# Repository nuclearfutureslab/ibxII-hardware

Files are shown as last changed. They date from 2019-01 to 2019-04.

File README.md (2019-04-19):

# IBX ]\[ Hardware

IBX ]\[ is an information barrier setup for nuclear warhead verification with an Apple II ([Details](http://www.vintageverification.org)).
This repository contains schematics and layout files for two custom Apple II peripheral cards.

The KiCad files use the [Apple \]\[ Edge Connector Template](http://www.xjmaas.nl/my-apple-collection/apple-edge-connector-template-for-kicad/), best place it inside the directory as (Apple2_Bus).

## ADC Board
Apple II peripheral card for A/D conversion of signals from radiation detectors (scintillator/photo multiplier combination). The card includes all necessary parts - pre-amplifier, amplification & pulse shaping, peak-detect and hold circuit, ADC timing circuit. The current revision is improved to use full +12V/-12V components all the way to the ADC. Previous versions included 8 LEDs that can be toggled by writing to a specific Apple II memory location, but these have been removed now.

[Rev. 3 Board at OSHPark repository](https://oshpark.com/shared_projects/9M42SHV2)
[Rev. 1 Board at OSHPark repository](https://oshpark.com/shared_projects/9M42SHV2)

### Address scheme (has to be offset by address of card slot, eg. 49344 for Slot 4):

| Address | R/W | Function |
|----| ----|----|
| 01 | (Read) | Reset trigger circuit, make it ready for a new incoming pulse |
| 02 | (Read) | Read low byte of ADC value |
| 03 | (Read) | Read high byte of ADC value |
| 04 | (Read) | Read status buffer for ADC |

## HV Board

Apple II peripheral card to provide high voltage supply to devices (e.g. Photo Multiplier tubes). The voltage is adjustable by writing an 8bit value to a memory address. It produces a voltage from 0-5V depending on this value, which gets converted into highvoltage by a CAEN 7505P module. 

[Rev. 1 Board at OSHPark repository](https://oshpark.com/shared_projects/YkaW1fvx)

### Address scheme (has to be offset by address of card slot, eg. 49312 for Slot 2):

| Address | R/W | Function |
|----| ----|----|
00 | (Write) | Address to write a value for DA
01 | (Read) | enable HV 
02 | (Read) | disable HV

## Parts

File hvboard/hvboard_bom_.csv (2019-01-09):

Component | Description | Part | References | Value | Footprint | Quantity Per PCB | Datasheet | DigiKey
1 |  | A2_BUS | BUS101 | A2_BUS | BUS_A2 | 1
2 | Unpolarized capacitor, small symbol | C_Small | C101 C103 C105 C106 C107 C109 | 0.1µF | FG18 | 6 | https://product.tdk.com/info/en/documents/chara_sheet/FG18X7R1H104KNT06.pdf | 445-173265-1-ND
3 | Unpolarized capacitor, small symbol | C_Small | C110 | 0.47µF | FG18 | 1 | https://product.tdk.com/info/en/documents/chara_sheet/FG18X7R1H474KRT06.pdf | 445-173276-1-ND
4 | Unpolarized capacitor, small symbol | C_Small | C104 C108 | 2.2µF | FG14 | 2 | https://product.tdk.com/info/en/documents/chara_sheet/FG14X7R1H225KRT06.pdf | 445-173138-1-ND
5 | Polarized capacitor, small US symbol | CP1_Small | C102 | 47µF | CP_Radial_D6.3mm_P2.50mm | 1 | https://industrial.panasonic.com/cdbs/www-data/pdf/RDF0000/ABA0000C1022.pdf | P15400-ND
6 | Light emitting diode | LED | D101 | LED | LED_D5.0mm | 1 | https://www.lumex.com/content/files/ProductAttachment/SSL-LX5093SID.pdf | 67-2288-ND
7 | Resettable fuse, polymeric positive temperature coefficient, small symbol | Polyfuse_Small | F101 F103 | Polyfuse_Small | Fuse_TE5_Littlefuse-395Series | 2 | https://product.tdk.com/info/en/documents/data_sheet/55/db/PTC/PTC_OC_Leaded_12V_24V_C935_C995.pdf | 495-3904-ND
8 | Generic connector, single row, 01x01, script generated (kicad-library-utils/schlib/autogen/connector/) | Conn_01x01 | J101 | Debug-1 | Socket_Strip_Straight_1x01_Pitch2.54mm | 1
9 | Generic connector, single row, 01x05, script generated (kicad-library-utils/schlib/autogen/connector/) | Conn_01x05 | J103 | Debug-2 | Pin_Header_Straight_1x05_Pitch2.54mm | 1
10 | coaxial connector (BNC, SMA, SMB, SMC, Cinch/RCA, ...) | Conn_Coaxial | J102 | HV | HVConnector3D | 1
11 | Resistor, small symbol | R_Small | R128 | 0 | Resistor | 1
12 | Resistor | R | R116 R118 R124 | 10k | Resistor | 3 | http://www.vishay.com/docs/28724/mrs16m25.pdf | PPC10.0KZCT-ND
13 | Resistor | R | R103 R105 R107 R109 R111 R113 R115 | 10k+ | Resistor | 7 | http://www.vishay.com/docs/28767/mbsmapre.pdf | BC4515CT-ND
14 | Resistor, small symbol | R_Small | R123 | 1M | Resistor | 1 | http://www.vishay.com/docs/28724/mrs16m25.pdf | BC3959CT-ND
15 | Resistor | R | R101 R102 R104 R106 R108 R110 R112 R114 R117 | 20k | Resistor | 9 | http://www.vishay.com/docs/28767/mbsmapre.pdf | BC4511CT-ND
16 | Resistor, small symbol | R_Small | R119 | 470 | Resistor | 1 | http://www.vishay.com/docs/28724/mrs16m25.pdf | BC4173CT-ND
17 | Resistor, small symbol | R_Small | R120 R121 R125 | 4k7 | Resistor | 3 | http://www.vishay.com/docs/28724/mrs16m25.pdf | BC4176CT-ND
18 | Resistor | R | R122 | 8k2 | Resistor | 1 | http://www.vishay.com/docs/28724/mrs16m25.pdf | BC4264CT-ND
19 | quad 2-input NAND gate | 7400 | U104 U105 | 74HCT00 | DIP-14 | 2 | http://www.ti.com/lit/gpn/sn74ls00 | 296-2081-5-ND
20 | Decoder 3 to 8 active low outputs | 74LS138 | U108 | 74HCT138 | DIP-16_W7.62mm | 1 | http://www.ti.com/lit/ds/symlink/cd74hc138.pdf | 296-2091-5-ND
21 | Hex inverter schmitt trigger | 74HC14 | U102 | 74HCT14 | DIP-14 | 1 | http://www.nxp.com/documents/data_sheet/74HC_HCT04.pdf | 296-2093-5-ND
22 | Dual D Flip-flop, Set & Reset | 74HC74 | U103 | 74HCT74 | DIP-14 | 1 | http://www.ti.com/lit/ds/symlink/cd74hc74.pdf | 296-2132-5-ND
23 | 8-bit Register, 3-state outputs | 74LS374 | U106 | 74LS374 | DIP-20_W7.62mm | 1 | http://www.ti.com/lit/ds/symlink/cd74hct374.pdf | 296-2115-5-ND
24 |  | AD584 | U101 | AD584 | DIP-8 | 1 | https://www.analog.com/media/en/technical-documentation/data-sheets/AD584.pdf | AD584KNZ-ND
25 |  | CHV | U107 | CHV | CHV-rev2 | 1
Component Groups: | 25
Component Count: | 51
Fitted Components: | 51
Number of PCBs: | 1
Total components: | 51
Schematic Version:
Schematic Date:
BoM Date: | Wed 09 Jan 2019 12:07:31 AM EST
Schematic Source: | /home/moritz/Sync/gdrive_princeton/workprojects/vintageibx/appleIIdev/ibxII-hardware/hvboard/hvboard.sch
KiCad Version: | Eeschema 5.0.2-bee76a0~70~ubuntu18.04.1

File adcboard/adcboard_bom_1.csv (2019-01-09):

Component | Description | Part | References | Value | Footprint | Quantity Per PCB | Datasheet | DigiKey
1 |  | A2_BUS | BUS1 | A2_BUS | BUS_ADC | 1
2 | Unpolarized capacitor, small symbol | C_Small | C5 C6 C9 C13 C19 C20 C21 C22 C23 C24 C25 C34 C35 | 100nF | FG18 | 13 | https://product.tdk.com/info/en/documents/chara_sheet/FG18X7R1H104KNT06.pdf | 445-173265-1-ND
3 | Unpolarized capacitor, small symbol | C_Small | C3 C4 C14 C18 C29 C30 C40 C41 C45 C46 | 10nF | FG18 | 10 | https://product.tdk.com/info/en/documents/chara_sheet/FG18X7R1H103KNT06.pdf | 445-173172-1-ND
4 | Unpolarized capacitor, small symbol | C_Small | C7 C10 | 10pF | FG18 | 2 | https://product.tdk.com/info/en/documents/chara_sheet/FG18C0G1H100DNT06.pdf | 445-173169-1-ND
5 | Unpolarized capacitor, small symbol | C_Small | C12 C16 C17 | 10µF | FG16 | 3 | https://product.tdk.com/info/en/documents/chara_sheet/FG16X5R1H106KRT06.pdf | 445-173153-1-ND
6 | Unpolarized capacitor, small symbol | C_Small | C31 C32 | 1µF | FG18 | 2 | https://product.tdk.com/info/en/documents/chara_sheet/FG18X5R1H105KRT06.pdf | 445-173257-1-ND
7 | Unpolarized capacitor, small symbol | C_Small | C11 | 2.2nF | FG18 | 1 | https://product.tdk.com/info/en/documents/chara_sheet/FG18C0G1H222JNT06.pdf | 445-173184-1-ND
8 | Unpolarized capacitor, small symbol | C_Small | C27 C28 C38 C39 | 2.2µF | FG14 | 4 | https://product.tdk.com/info/en/documents/chara_sheet/FG14X7R1H225KRT06.pdf | 445-173138-1-ND
9 | Unpolarized capacitor, small symbol | C_Small | C1 C2 C43 C44 | 3.3µF | FG14 | 4 | https://product.tdk.com/info/en/documents/chara_sheet/FG14X5R1H335KRT06.pdf | 445-173130-1-ND
10 | Unpolarized capacitor, small symbol | C_Small | C15 | 330pF | FG18 | 1 | https://product.tdk.com/info/en/documents/chara_sheet/FG18C0G1H331JNT06.pdf | 445-173190-1-ND
11 | Unpolarized capacitor, small symbol | C_Small | C26 C36 C37 C42 | 470pF | FG28 | 4 | https://product.tdk.com/info/en/documents/chara_sheet/FG28C0G1H471JNT06.pdf | 445-173500-1-ND
12 | Unpolarized capacitor, small symbol | C_Small | C8 | 470pF | FG18 | 1 | https://product.tdk.com/info/en/documents/chara_sheet/FG18C0G1H471JNT06.pdf | 445-173197-1-ND
13 | Unpolarized capacitor, small symbol | C_Small | C33 | 47pF | FG28 | 1 | https://product.tdk.com/info/en/documents/chara_sheet/FG28C0G1H470JNT06.pdf | 445-173499-1-ND
14 | Zener diode, small symbol | D_Zener_Small | D5 | D_Zener_Small | D_DO-35_SOD27_P7.62mm_Horizontal | 1 | http://www.vishay.com/docs/85604/bzx55-se.pdf | BZX55B10-TRGICT-ND
15 | Light emitting diode, small symbol | LED_Small | D4 | LED_Small | LED_D5.0mm | 1 | https://www.lumex.com/content/files/ProductAttachment/SSL-LX5093USBD.pdf | 67-1751-ND
16 | Schottky diode, small symbol | D_Schottky_Small | D1 D2 D3 | SD103A | D_DO-35_SOD27_P7.62mm_Horizontal | 3 | http://www.vishay.com/docs/85754/sd103a.pdf | SD103AVSCT-ND
17 | Resettable fuse, polymeric positive temperature coefficient, small symbol | Polyfuse_Small | F2 | HC:120mA | Fuse_Littelfuse_395Series | 1 | https://product.tdk.com/info/en/documents/data_sheet/55/db/PTC/PTC_OC_Leaded_12V_24V_C935_C995.pdf | 495-3907-ND
18 | Resettable fuse, polymeric positive temperature coefficient, small symbol | Polyfuse_Small | F1 F3 | HC:250mA | Fuse_Littelfuse_395Series | 2 | https://product.tdk.com/info/en/documents/data_sheet/55/db/PTC/PTC_OC_Leaded_12V_24V_C935_C995.pdf | 495-3904-ND
19 | coaxial connector (BNC, SMA, SMB, SMC, Cinch/RCA, ...) | Conn_Coaxial | J2 | Detector | BNC_Socket_TYCO-AMP_LargePads | 1 | https://www.te.com/commerce/DocumentDelivery/DDEController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 | A97555-ND
20 | Generic connector, single row, 01x03, script generated (kicad-library-utils/schlib/autogen/connector/) | Conn_01x03 | J4 | SigADC | 3-Pin-Header | 1 | ~
21 | Generic connector, single row, 01x03, script generated (kicad-library-utils/schlib/autogen/connector/) | Conn_01x03 | J8 | SigDiff | 3-Pin-Header | 1 | ~
22 | Generic connector, single row, 01x03, script generated (kicad-library-utils/schlib/autogen/connector/) | Conn_01x03 | J5 | SigF1 | 3-Pin-Header | 1 | ~
23 | Generic connector, single row, 01x03, script generated (kicad-library-utils/schlib/autogen/connector/) | Conn_01x03 | J7 | SigF2 | 3-Pin-Header | 1 | ~
24 | Generic connector, single row, 01x03, script generated (kicad-library-utils/schlib/autogen/connector/) | Conn_01x03 | J9 | SigF3 | 3-Pin-Header | 1 | ~
25 | Generic connector, single row, 01x03, script generated (kicad-library-utils/schlib/autogen/connector/) | Conn_01x03 | J10 | SigInv | 3-Pin-Header | 1 | ~
26 | Generic connector, single row, 01x03, script generated (kicad-library-utils/schlib/autogen/connector/) | Conn_01x03 | J1 | SigOut | 3-Pin-Header | 1 | ~
27 | Generic connector, single row, 01x03, script generated (kicad-library-utils/schlib/autogen/connector/) | Conn_01x03 | J6 | SigP | 3-Pin-Header | 1 | ~
28 | Generic connector, single row, 01x03, script generated (kicad-library-utils/schlib/autogen/connector/) | Conn_01x03 | J3 | TrigLvl | 3-Pin-Header | 1 | ~
29 | Resistor, small symbol | R_Small | R7 R9 R11 | 100 | Resistor | 3 | http://www.vishay.com/docs/28724/mrs16m25.pdf | BC3952CT-ND
30 | Resistor, small symbol | R_Small | R10 R13 R28 | 10k | Resistor | 3 | http://www.vishay.com/docs/28724/mrs16m25.pdf | PPC10.0KZCT-ND
31 | Resistor, small symbol | R_Small | R21 | 150k | Resistor | 1 | http://www.vishay.com/docs/28724/mrs16m25.pdf | PPC150KZCT-ND
32 | Resistor, small symbol | R_Small | R23 R27 R32 | 15k | Resistor | 3 | http://www.vishay.com/docs/28724/mrs16m25.pdf | BC4005CT-ND
33 | Resistor, small symbol | R_Small | R3 | 1k | Resistor | 1 | http://www.vishay.com/docs/28724/mrs16m25.pdf | PPC1.00KZCT-ND
34 | Resistor, small symbol | R_Small | R6 | 200 | Resistor | 1 | http://www.vishay.com/docs/28724/mrs16m25.pdf | BC4039CT-ND
35 | Resistor, small symbol | R_Small | R22 R26 R31 | 20k | Resistor | 3 | http://www.vishay.com/docs/28724/mrs16m25.pdf | PPC20.0KZCT-ND
36 | Resistor, small symbol | R_Small | R8 | 330 | Resistor | 1 | http://www.vishay.com/docs/28724/mrs16m25.pdf | BC4123CT-ND
37 | Resistor, small symbol | R_Small | R2 R30 | 47k | Resistor | 2 | http://www.vishay.com/docs/28724/mrs16m25.pdf | BC4178CT-ND
38 | Resistor, small symbol | R_Small | R18 R19 | 49.9 | Resistor | 2 | http://www.vishay.com/docs/28724/mrs16m25.pdf | BC4639CT-ND
39 | Resistor, small symbol | R_Small | R12 R14 R15 R16 R17 R33 | 4k7 | Resistor | 6 | http://www.vishay.com/docs/28724/mrs16m25.pdf | BC4176CT-ND
40 | Resistor, small symbol | R_Small | R4 | 510 | Resistor | 1 | http://www.vishay.com/docs/28724/mrs16m25.pdf | BC4190CT-ND
41 | Resistor, small symbol | R_Small | R1 R5 | 6k8 | Resistor | 2 | http://www.vishay.com/docs/28724/mrs16m25.pdf | BC4239CT-ND
42 | Resistor, small symbol | R_Small | R20 R24 R25 R29 | 8k2 | Resistor | 4 | http://www.vishay.com/docs/28724/mrs16m25.pdf | BC4264CT-ND
43 | Potentiometer | R_POT | RV2 | 100k | Potentiometer_Bourns_3006P_Horizontal | 1 | https://www.bourns.com/docs/Product-Datasheets/3006.pdf | 3006P-104LF-ND
44 | Potentiometer | R_POT | RV1 | 50k | Potentiometer_Bourns_3006P_Horizontal | 1 | https://www.bourns.com/docs/Product-Datasheets/3006.pdf | 3006P-503LF-ND
45 | quad 2-input NAND gate | 7400 | U6 U7 | 74HCT00 | DIP-14 | 2 | http://www.ti.com/lit/ds/symlink/cd74hc74.pdf | 296-2081-5-ND
46 | hex inverter | 74HC04 | U5 U9 | 74HCT04 | DIP-14 | 2 | http://www.ti.com/lit/ds/symlink/cd74hc04.pdf | 296-2083-5-ND
47 | Decoder 3 to 8 active low outputs | 74LS138 | U8 | 74HCT138 | DIP-16_W7.62mm_Socket | 1 | http://www.ti.com/lit/ds/symlink/cd74hc138.pdf | 296-2091-5-ND
48 | 8-bit Buffer/Line Driver 3-state | 74HC244 | U11 | 74HCT244 | DIP-20_W7.62mm_Socket | 1 | http://www.ti.com/lit/ds/symlink/cd74hc240.pdf | 296-2104-5-ND
49 | Dual D Flip-flop, Set & Reset | 74HC74 | U4 | 74HCT74 | DIP-14 | 1 | http://www.ti.com/lit/ds/symlink/cd74hc74.pdf | 296-2132-5-ND
50 | Single Rail-to-Rail High Output Current Operational Amplifiers, SOIC-8 | OP179GS | U13 | AD744 | DIP-8 | 1 | http://www.analog.com/media/en/technical-documentation/data-sheets/OP179_279.pdf | AD744KNZ-ND
51 |  | AD790 | U3 | AD790 | DIP-8 | 1 | https://www.analog.com/media/en/technical-documentation/data-sheets/AD790.pdf | AD790JNZ-ND
52 | Dual operational amplifier | Opamp_Dual_Generic | U1 | AD826 | DIP-8 | 1 | https://www.analog.com/media/en/technical-documentation/data-sheets/AD826.pdf | AD826ANZ-ND
53 | Dual High Speed, Low Power, Low Distortion, Voltage Feedback Amplifiers, DIP-8/SOIC-8 | LM6172 | U15 | AD826 | DIP-8 | 1 | https://www.analog.com/media/en/technical-documentation/data-sheets/AD826.pdf | AD826ANZ-ND
54 |  | ADC-AD1674 | U10 | ADC-AD1674 | DIP-28_W15.24mm_Socket | 1 | https://www.analog.com/media/en/technical-documentation/data-sheets/AD1674.pdf | AD1674JNZ-ND
55 | Single SPST Monolithic CMOS Analog Switch, normally OFF, 20Ohm Ron, DIP-8 | DG418xJ | U2 | DG418 | DIP-8 | 1 | http://www.vishay.com/docs/70051/dg417.pdf | DG418DJ-E3-ND
56 | Dual High Speed, Low Power, Low Distortion, Voltage Feedback Amplifiers, DIP-8/SOIC-8 | LM6172 | U12 U14 | LM6172 | DIP-8 | 2 | http://www.ti.com/lit/ds/symlink/lm6172.pdf | LM6172IN/NOPB-ND
Component Groups: | 56
Component Count: | 115
Fitted Components: | 115
Number of PCBs: | 1
Total components: | 115
Schematic Version: | 1
Schematic Date: | 2017-11-28
BoM Date: | Tue 08 Jan 2019 11:19:12 PM EST
Schematic Source: | /home/moritz/Sync/gdrive_princeton/workprojects/vintageibx/appleIIdev/ibxII-hardware/adcboard/adcboard.sch
KiCad Version: | Eeschema 5.0.2-bee76a0~70~ubuntu18.04.1

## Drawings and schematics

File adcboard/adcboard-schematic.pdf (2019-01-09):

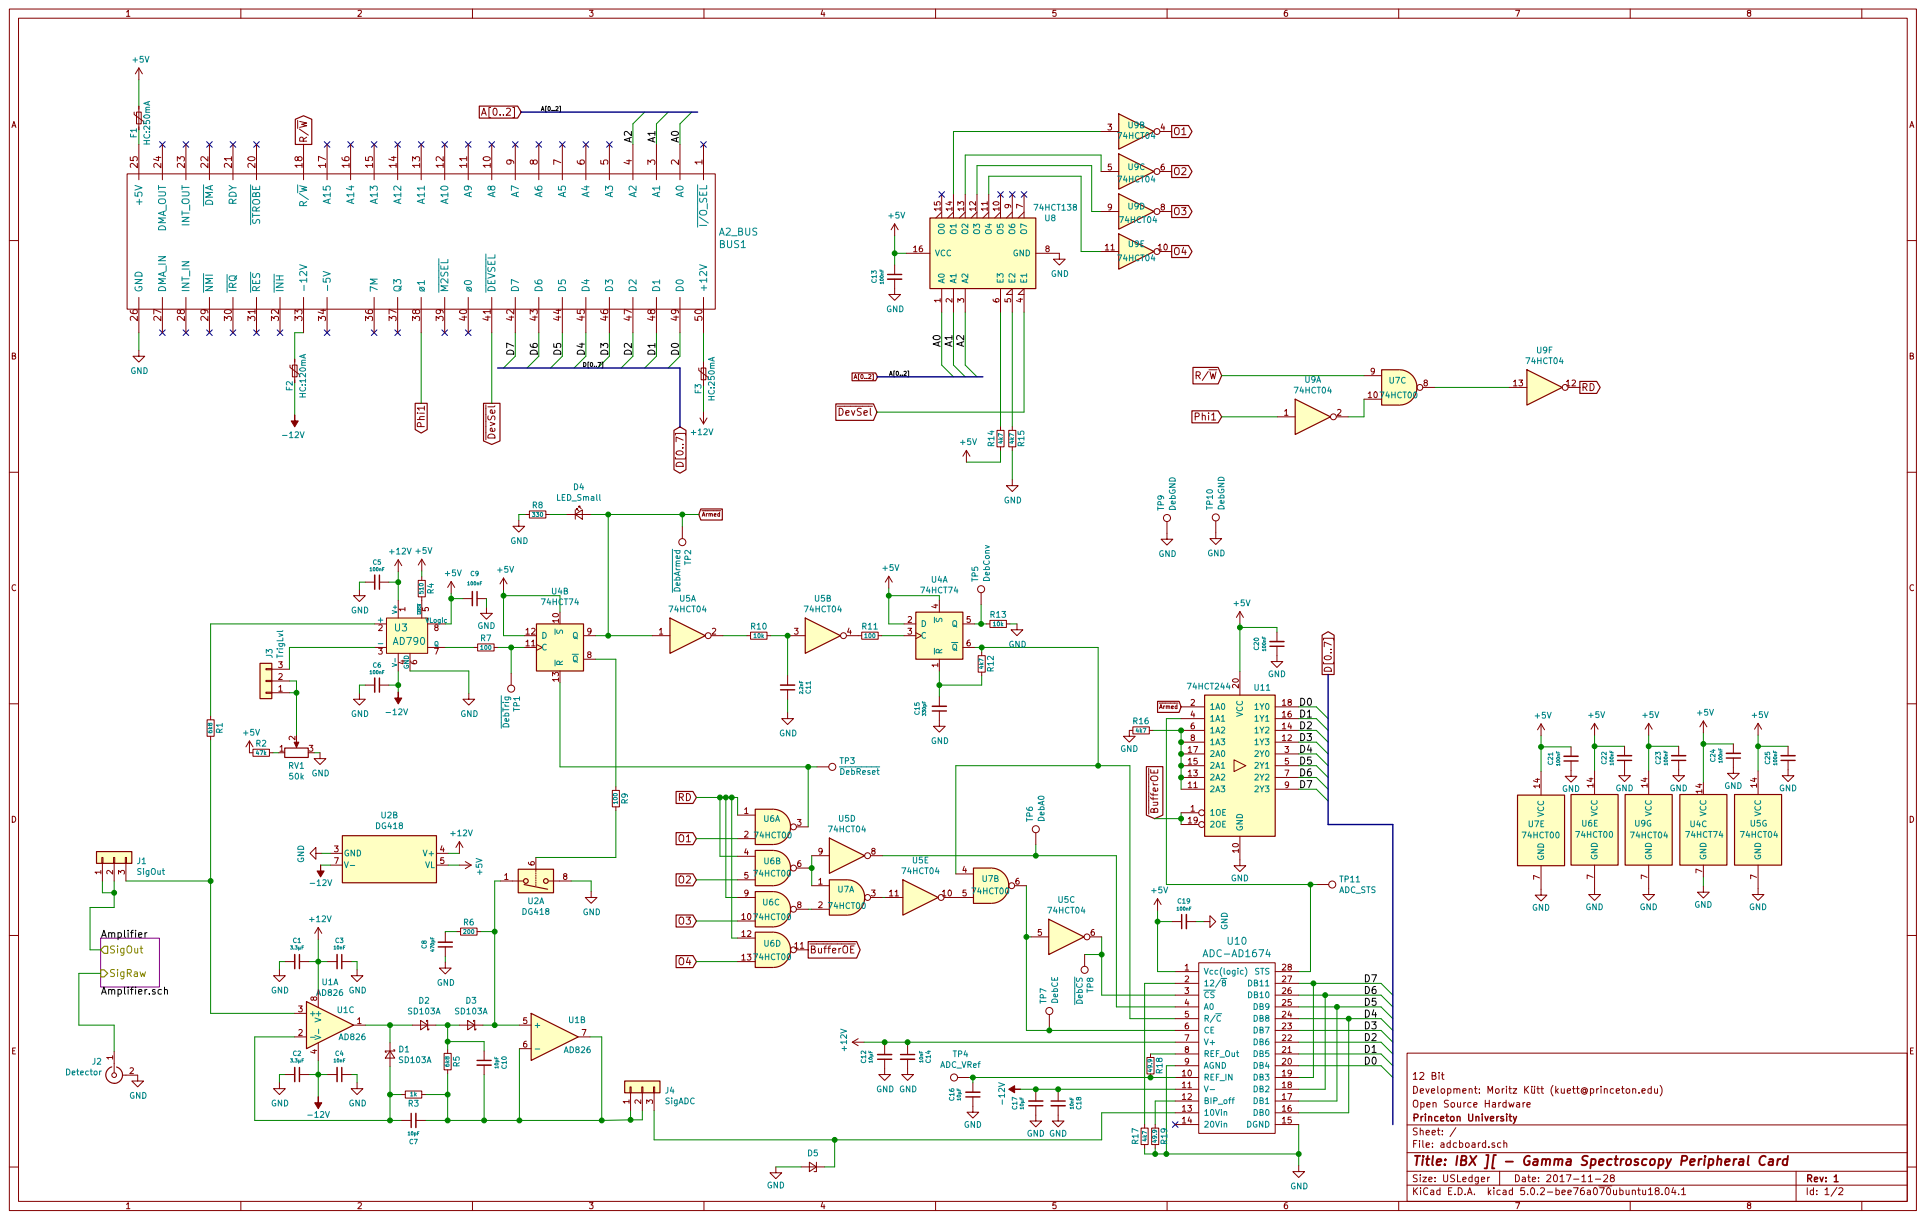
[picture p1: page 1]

9 A8 10 STROBE 20 IRQ 30 ø0 40 +12V 50 A9 11 RDY 21 RES 31 DEVSEL 41 A10 12 DMA 22 INH 32 D7 42 A11 13 INT_OUT 23 -12V 33 D6 43 A12 14 DMA_OUT 24 -5V 34 D5 44 A13 15 +5V 25 D4 45 A14 16 GND 26 7M 36 D3 46 A15 17 DMA_IN 27 Q3 37 D2 47 R/W 18 INT_IN 28 ø1 38 D1 48 NMI 29 M2SEL 39 D0 49 BUS1 A2_BUS

File: adcboard.sch Sheet: / Princeton University Open Source Hardware Development: Moritz Kütt (kuett@princeton.edu) 12 Bit A0A1A2

Amplifier Amplifier.sch SigRaw

Id: 1/2 Title: IBX ][ - Gamma Spectroscopy Peripheral Card

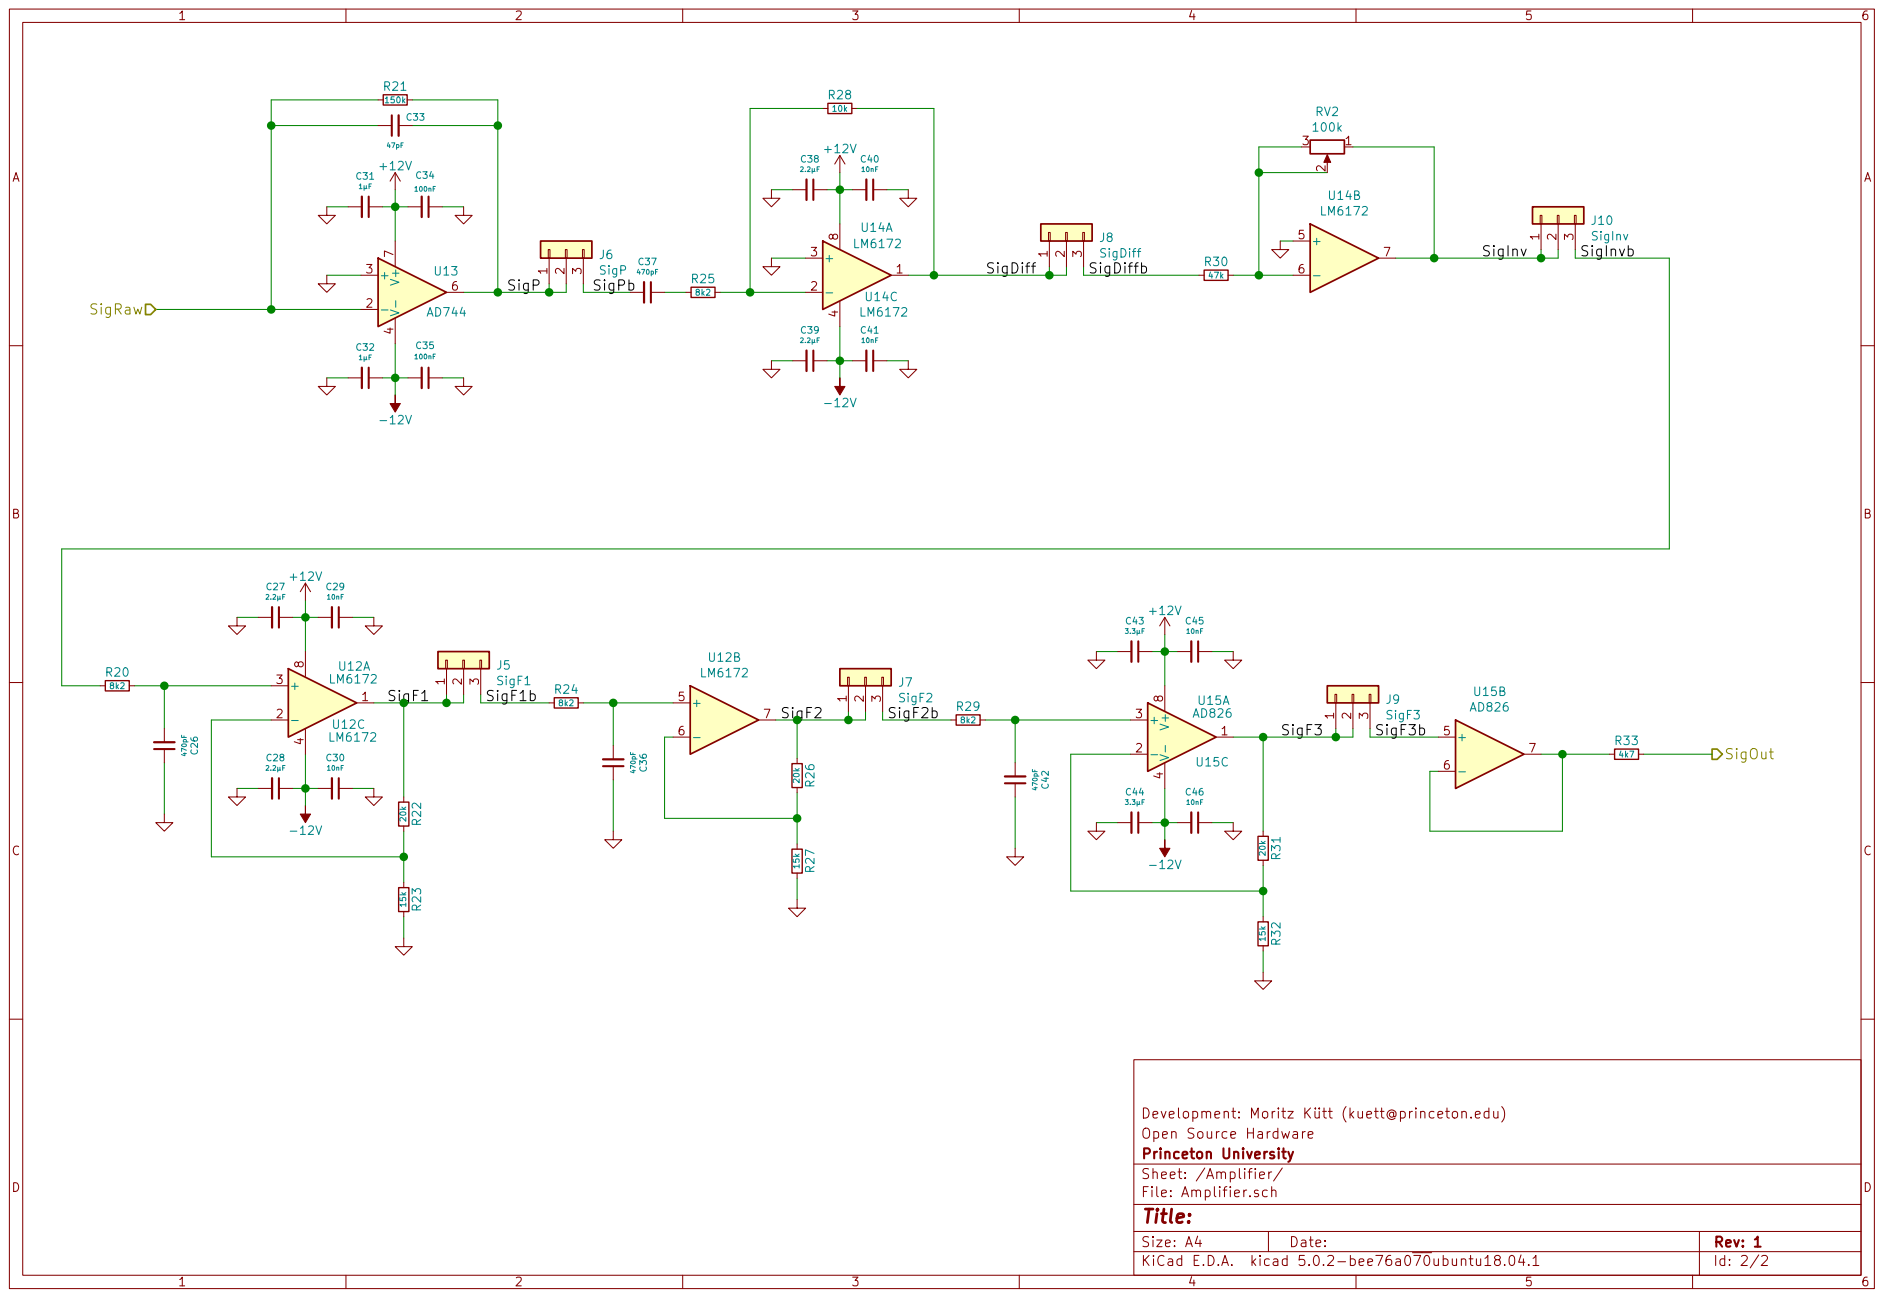
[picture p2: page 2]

Development: Moritz Kütt (kuett@princeton.edu)
Open Source Hardware
Princeton University
Sheet: /Amplifier/
File: Amplifier.sch
Id: 2/2 Title:

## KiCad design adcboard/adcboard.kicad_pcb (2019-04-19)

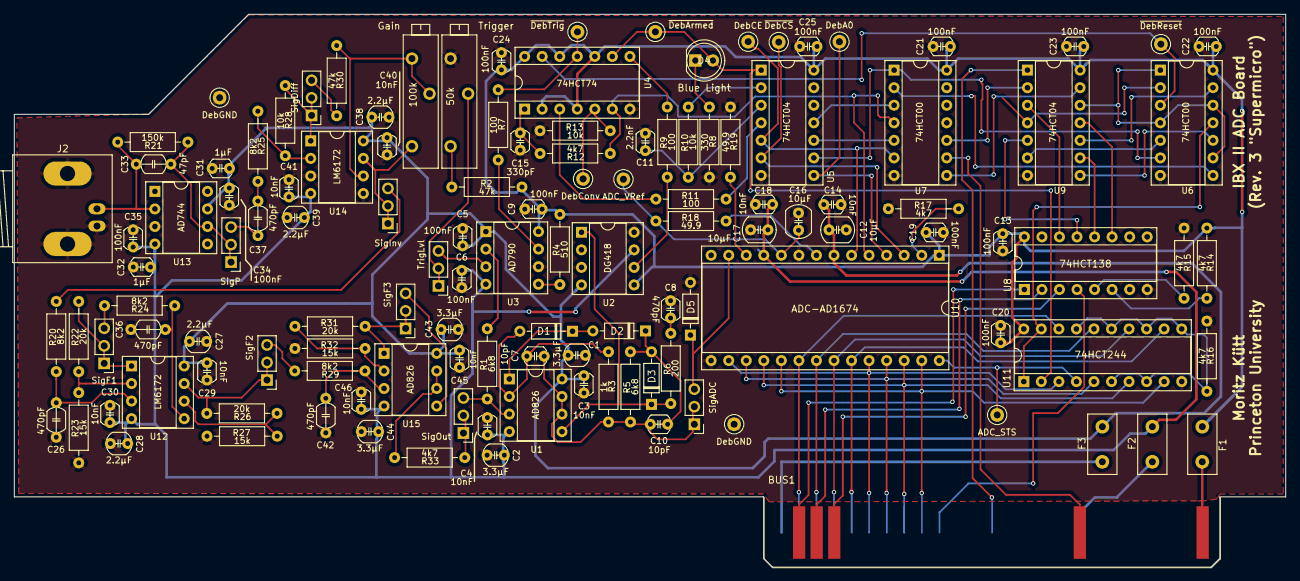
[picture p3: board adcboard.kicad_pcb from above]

Board: 2 copper layers, 184.0 x 80.0 mm, 126 parts (0 on the bottom side), 99 nets.

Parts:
BUS1: A2_BUS; BUS_ADC
C1, C2, C43, C44: 3.3µF; FG14
C3, C4, C14, C18, C29, C30, C40, C41, C45, C46: 10nF; FG18
C5, C6, C9, C13, C19, C20, C21, C22, C23, C24, C25, C34, C35: 100nF; FG18
C7, C10: 10pF; FG18
C8: 470pF; FG18
C11: 2.2nF; FG18
C12, C16, C17: 10µF; FG16
C15: 330pF; FG18
C26, C36, C37, C42: 470pF; FG28
C27, C28, C38, C39: 2.2µF; FG14
C31, C32: 1µF; FG18
C33: 47pF; FG28
D1, D2, D3: SD103A; D_DO-35_SOD27_P7.62mm_Horizontal
D4: Blue Light; LED_D5.0mm
D5: D_Zener_Small; D_DO-35_SOD27_P7.62mm_Horizontal
F1, F3: HC:250mA; Fuse_Littelfuse_395Series
F2: HC:120mA; Fuse_Littelfuse_395Series
Gain: 100k; Potentiometer_Bourns_3006P_Horizontal
J1: SigOut; 3-Pin-Header
J2: Detector; BNC_Socket_TYCO-AMP_LargePads
J3: TrigLvl; 3-Pin-Header
J4: SigADC; 3-Pin-Header
J5: SigF1; 3-Pin-Header
J6: SigP; 3-Pin-Header
J7: SigF2; 3-Pin-Header
J8: SigDiff; 3-Pin-Header
J9: SigF3; 3-Pin-Header
J10: SigInv; 3-Pin-Header
R1, R5: 6k8; Resistor
R2, R30: 47k; Resistor
R3: 1k; Resistor
R4: 510; Resistor
R6: 200; Resistor
R7, R9, R11: 100; Resistor
R8: 330; Resistor
R10, R13, R28: 10k; Resistor
R12, R14, R15, R16, R17, R33: 4k7; Resistor
R18, R19: 49.9; Resistor
R20, R24, R25, R29: 8k2; Resistor
R21: 150k; Resistor
R22, R26, R31: 20k; Resistor
R23, R27, R32: 15k; Resistor
TP1: ~DebTrig; TP
TP2: ~DebArmed; TP
TP3: ~DebReset; TP
TP4: ADC_VRef; TP
TP5: DebConv; TP
TP6: DebA0; TP
TP7: DebCE; TP
TP8: ~DebCS; TP
TP9, TP10: DebGND; TP
TP11: ADC_STS; TP
Trigger: 50k; Potentiometer_Bourns_3006P_Horizontal
U1, U15: AD826; DIP-8
U2: DG418; DIP-8
U3: AD790; DIP-8
U4: 74HCT74; DIP-14
U5, U9: 74HCT04; DIP-14
U6, U7: 74HCT00; DIP-14
U8: 74HCT138; DIP-16_W7.62mm_Socket
U10: ADC-AD1674; DIP-28_W15.24mm_Socket
U11: 74HCT244; DIP-20_W7.62mm_Socket
U12, U14: LM6172; DIP-8
U13: AD744; DIP-8

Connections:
+5V: C9.2, C13.1, C19.1, C20.2, C21.2, C22.2, C23.2, C24.2, C25.2, F1.1, R2.2, R4.2, R14.1, U2.5, U3.8, U4.2, U4.4, U4.10, U4.12, U4.14, U5.14, U6.14, U7.14, U8.16, U9.14, U10.1, U11.20
+12V: C1.1, C3.2, C5.1, C12.2, C14.1, C27.1, C29.2, C31.1, C34.2, C38.1, C40.2, C43.1, C45.2, F3.2, U1.8, U2.4, U3.1, U10.7, U12.8, U13.7, U14.8, U15.8
-12V: C2.1, C4.2, C6.1, C17.2, C18.1, C28.1, C30.2, C32.1, C35.2, C39.1, C41.2, C44.1, C46.2, F2.2, U1.4, U2.7, U3.4, U10.11, U12.4, U13.4, U14.4, U15.4
/Amplifier/SigDiff: J8.1, J8.2, R28.1, U14.1
/Amplifier/SigDiffb: J8.3, R30.2
/Amplifier/SigF1: J5.1, J5.2, R22.2, U12.1
/Amplifier/SigF1b: J5.3, R24.2
/Amplifier/SigF2: J7.1, J7.2, R26.2, U12.7
/Amplifier/SigF2b: J7.3, R29.2
/Amplifier/SigF3: J9.1, J9.2, R31.2, U15.1
/Amplifier/SigF3b: J9.3, U15.5
/Amplifier/SigInv: Gain.1, J10.1, J10.2, U14.7
/Amplifier/SigInvb: J10.3, R20.2
/Amplifier/SigOut: J1.1, J1.2, R33.1
/Amplifier/SigP: C33.2, J6.1, J6.2, R21.1, U13.6
/Amplifier/SigPb: C37.2, J6.3
/Amplifier/SigRaw: C33.1, J2.1, R21.2, U13.2
A0: BUS1.2, U8.1
A1: BUS1.3, U8.2
A2: BUS1.4, U8.3
D0: BUS1.49, U10.20, U11.18
D1: BUS1.48, U10.21, U11.16
D2: BUS1.47, U10.22, U11.14
D3: BUS1.46, U10.23, U11.12
D4: BUS1.45, U10.16, U10.24, U11.3
D5: BUS1.44, U10.17, U10.25, U11.5
D6: BUS1.43, U10.18, U10.26, U11.7
D7: BUS1.42, U10.19, U10.27, U11.9
GND: BUS1.26, C1.2, C2.2, C3.1, C4.1, C5.2, C6.2, C8.1, C9.1, C11.1, C12.1, C13.2, C14.2, C15.1, C16.1, C17.1, C18.2, C19.2, C20.1, C21.1, C22.1, C23.1, C24.1, C25.1, C26.1, C27.2, C28.2, C29.1, C30.1, C31.2, C32.2, C34.1, C35.1, C36.1, C38.2, C39.2, C40.1, C41.1, C42.1, C43.2, C44.2, C45.1, C46.1, D5.2, J2.2, R8.2, R13.1, R15.1, R16.1, R17.1, R19.1, R23.1, R27.1, R32.1, TP9.1, TP10.1, Trigger.3, U2.3, U2.8, U3.6, U4.7, U5.7, U6.7, U7.7, U8.8, U9.7, U10.9, U10.15, U11.10, U13.3, U14.3, U14.5
unnamed: BUS1.25, F1.2
unnamed: BUS1.33, F2.1
unnamed: BUS1.50, F3.1
unnamed: C7.1, D1.2, R3.1, U1.2
unnamed: C8.2, R6.2
unnamed: C10.1, D2.1, D3.2, R5.2
unnamed: C7.2, C10.2, J4.1, J4.2, R3.2, R5.1, U1.6, U1.7
unnamed: C11.2, R10.1, U5.3
unnamed: C15.2, R12.2, U4.1
unnamed: C16.2, R18.1, TP4.1, U10.10
unnamed: C26.2, R20.1, U12.3
unnamed: C36.2, R24.1, U12.5
unnamed: C37.1, R25.2
unnamed: C42.2, R29.1, U15.3
unnamed: D1.1, D2.2, U1.1
unnamed: D3.1, R6.1, U1.5, U2.1
unnamed: D4.1, R8.1
unnamed: D5.1, J4.3, U10.13
unnamed: J1.3, R1.1, U1.3
unnamed: J3.1, J3.2, Trigger.2
unnamed: J3.3, U3.3
unnamed: R1.2, U3.2
unnamed: R2.1, Trigger.1
unnamed: R4.1, U3.5
unnamed: R7.1, TP1.1, U4.11
unnamed: R7.2, U3.7
unnamed: R9.1, U2.6
unnamed: R9.2, U4.8
unnamed: R10.2, U5.2
unnamed: R11.1, U4.3
unnamed: R11.2, U5.4
unnamed: R12.1, U4.6, U7.4, U10.5
unnamed: R13.2, TP5.1, U4.5
unnamed: R14.2, U8.6
unnamed: R15.2, U8.5
unnamed: R16.2, U11.6, U11.8, U11.11, U11.13, U11.15, U11.17
unnamed: R17.2, U10.2
unnamed: R18.2, U10.8
unnamed: R19.2, U10.12
unnamed: R22.1, R23.2, U12.2
unnamed: R25.1, R28.2, U14.2
unnamed: R26.1, R27.2, U12.6
unnamed: Gain.2, Gain.3, R30.1, U14.6
unnamed: R31.1, R32.2, U15.2
unnamed: R33.2, U15.6, U15.7
unnamed: TP3.1, U4.13, U6.3
unnamed: TP6.1, U5.8, U10.4
unnamed: TP7.1, U5.5, U7.6, U10.6
unnamed: TP8.1, U5.6, U10.3
unnamed: TP11.1, U10.28, U11.4
unnamed: U5.9, U6.6, U7.1
unnamed: U5.10, U7.5
unnamed: U5.11, U7.3
unnamed: U6.8, U7.2
unnamed: U7.8, U9.13
unnamed: U7.10, U9.2
unnamed: U8.11, U9.11
unnamed: U8.12, U9.9
unnamed: U8.13, U9.5
unnamed: U8.14, U9.3
O1: U6.2, U9.4
O2: U6.5, U9.6
O3: U6.10, U9.8
O4: U6.13, U9.10
Phi1: BUS1.38, U9.1
R/~W: BUS1.18, U7.9
RD: U6.1, U6.4, U6.9, U6.12, U9.12
~Armed: D4.2, TP2.1, U4.9, U5.1, U11.2
~BufferOE: U6.11, U11.1, U11.19
~DevSel: BUS1.41, U8.4

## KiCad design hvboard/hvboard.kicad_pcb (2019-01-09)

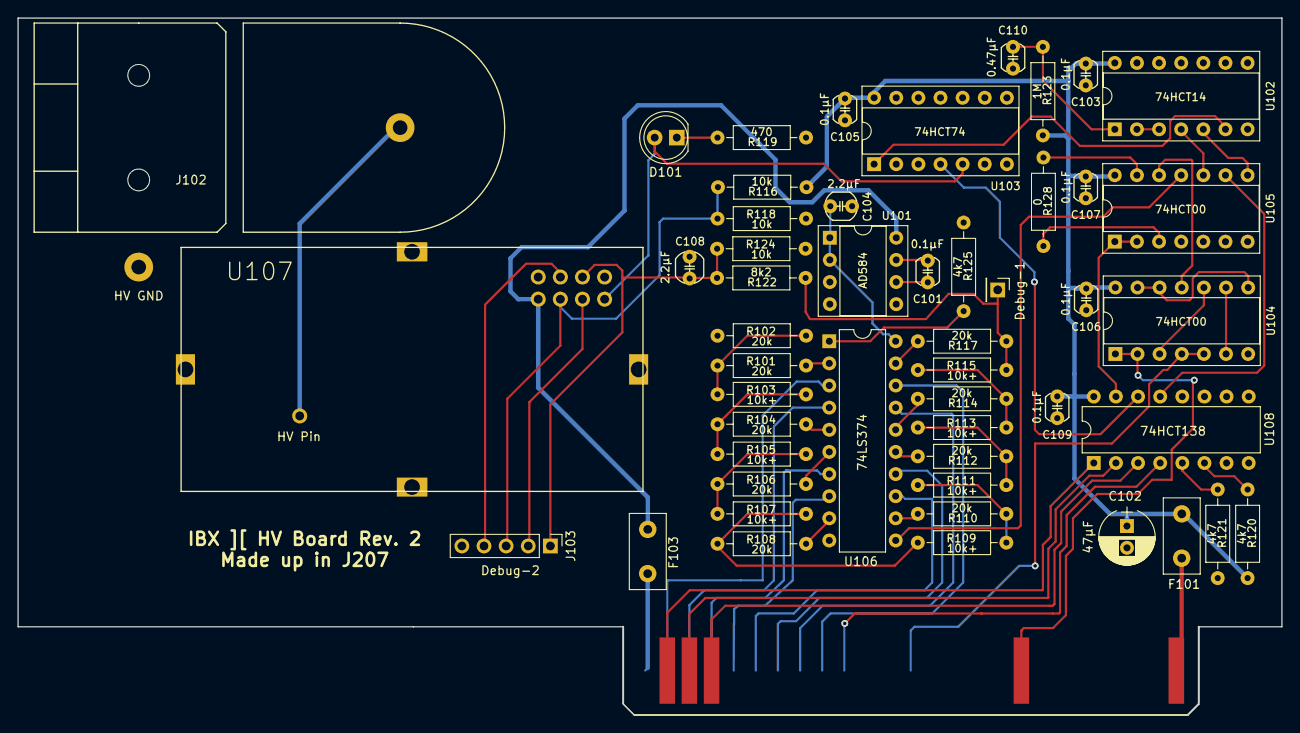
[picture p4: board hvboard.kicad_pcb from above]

Board: 2 copper layers, 145.0 x 80.0 mm, 51 parts (0 on the bottom side), 63 nets.

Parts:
BUS101: A2_BUS; BUS_A2
C101, C103, C105, C106, C107, C109: 0.1µF; FG18
C102: 47µF; CP_Radial_D6.3mm_P2.50mm
C104, C108: 2.2µF; FG14
C110: 0.47µF; FG18
D101: LED; LED_D5.0mm
F101, F103: Polyfuse_Small; Fuse_TE5_Littlefuse-395Series
J101: Debug-1; Socket_Strip_Straight_1x01_Pitch2.54mm
J102: HV; HVConnector3D
J103: Debug-2; Pin_Header_Straight_1x05_Pitch2.54mm
R101, R102, R104, R106, R108, R110, R112, R114, R117: 20k; Resistor
R103, R105, R107, R109, R111, R113, R115: 10k+; Resistor
R116, R118, R124: 10k; Resistor
R119: 470; Resistor
R120, R121, R125: 4k7; Resistor
R122: 8k2; Resistor
R123: 1M; Resistor
R128: 0; Resistor
U101: AD584; DIP-8
U102: 74HCT14; DIP-14
U103: 74HCT74; DIP-14
U104, U105: 74HCT00; DIP-14
U106: 74LS374; DIP-20_W7.62mm
U107: CHV; CHV-rev2
U108: 74HCT138; DIP-16_W7.62mm

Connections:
+5V: C102.1, C103.2, C105.2, C106.2, C107.2, C109.2, F101.1, R116.1, R120.2, R123.2, U102.14, U103.14, U104.14, U105.14, U108.16
+12V: F103.1, U101.8, U107.7
/D0: BUS101.49, U106.3
/D1: BUS101.48, U106.4
/D2: BUS101.47, U106.7
/D3: BUS101.46, U106.8
/D4: BUS101.45, U106.13
/D5: BUS101.44, U106.14
/D6: BUS101.43, U106.17
/D7: BUS101.42, U106.18
GND: BUS101.26, C102.2, C103.1, C104.1, C105.1, C106.1, C107.1, C108.1, C109.1, C110.2, J102.2, J103.5, R102.1, R118.2, R119.1, R121.2, R124.2, R125.1, U101.4, U102.7, U103.2, U103.3, U103.7, U104.7, U105.7, U106.10, U107.8, U107.S1, U107.S2, U107.S3, U107.S4, U108.8
unnamed: BUS101.2, U108.1
unnamed: BUS101.3, U108.2
unnamed: BUS101.4, U108.3
unnamed: BUS101.18, U104.1, U104.2
unnamed: BUS101.25, F101.2
unnamed: BUS101.38, U104.4, U104.5
unnamed: BUS101.41, U108.4
unnamed: BUS101.50, F103.2
unnamed: C101.1, U101.6
unnamed: C101.2, U101.7
unnamed: C104.2, U101.1, U101.2, U106.20
unnamed: C108.2, J103.1, R122.2, R124.1, U107.4
unnamed: C110.1, R123.1, U102.1
unnamed: D101.1, R119.2
unnamed: D101.2, U103.5, U107.1
unnamed: J101.1, R115.2, R117.1, R122.1
unnamed: J102.1, U107.9
unnamed: J103.2, U107.3
unnamed: J103.3, R116.2, R118.1, U107.5
unnamed: J103.4, U107.6
unnamed: R101.1, R102.2, R103.1
unnamed: R101.2, U106.2
unnamed: R103.2, R104.1, R105.1
unnamed: R104.2, U106.5
unnamed: R105.2, R106.1, R107.1
unnamed: R106.2, U106.6
unnamed: R107.2, R108.1, R109.1
unnamed: R108.2, U106.9
unnamed: R109.2, R110.1, R111.1
unnamed: R110.2, U106.12
unnamed: R111.2, R112.1, R113.1
unnamed: R112.2, U106.15
unnamed: R113.2, R114.1, R115.1
unnamed: R114.2, U106.16
unnamed: R117.2, U106.19
unnamed: R120.1, U108.6
unnamed: R121.1, U108.5
unnamed: R125.2, U106.1
unnamed: R128.1, U105.13
unnamed: R128.2, U105.3
unnamed: U102.2, U102.3
unnamed: U102.4, U105.10
unnamed: U102.5, U105.8
unnamed: U102.6, U103.1
unnamed: U103.4, U108.14
unnamed: U104.6, U104.9
unnamed: U104.3, U104.10
unnamed: U104.11, U105.12
unnamed: U104.8, U104.12, U104.13
unnamed: U105.1, U105.2, U108.15
unnamed: U105.9, U108.13
unnamed: U105.11, U106.11

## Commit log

2019-01-09 Changes for Kicad 5
    [Amplifier.sch, LED.sch, adcboard.kicad_pcb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]
2019-01-09 Rev. 3 of ADC board, full 12V rail for analog
    [200.sch, 400.sch, Amplifier.sch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]
2019-01-09 Update to footprint library
2019-01-09 ADC Rev. 3 gerber files
    [adcboard-B.Mask.gbs, adcboard-Edge.Cuts.gm1, adcboard-F.Cu.gtl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]
2019-01-09 HV board - KiCad 5 and small footprint changes
    [hvboard.csv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]
2019-04-19 remove gerber files
    [adcboard-B.Mask.gbs, adcboard-Edge.Cuts.gm1, adcboard-F.Cu.gtl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]
2019-04-19 minor revision
    [adcboard.kicad_pcb]
